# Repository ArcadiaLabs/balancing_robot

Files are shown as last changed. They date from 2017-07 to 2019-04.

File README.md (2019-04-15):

# Android Controlled Self Balancing Robot
Arduino + Android remote controlled balancing robot

This project is on Hackaday.io and takes part in the Hackaday Prize 2017 : https://hackaday.io/project/25835-android-controlled-balancing-robot
**Like this project on Hackaday.io and help me build new cool things !**

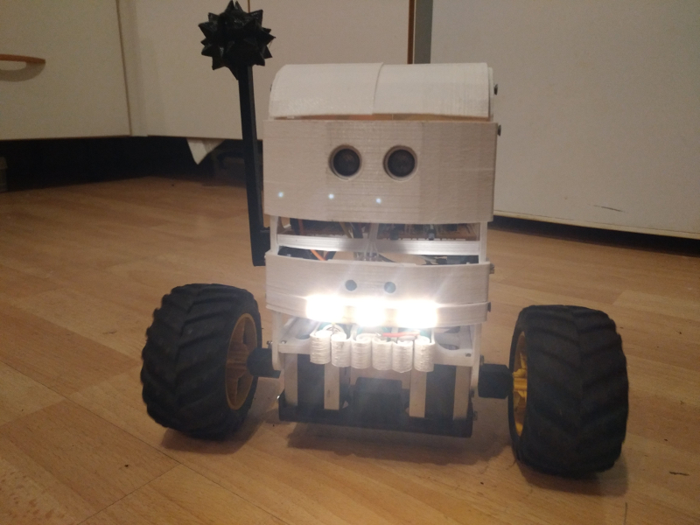
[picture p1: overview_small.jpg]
Overview


- Arduino pro micro (atmega32u4)
- Balance-Bot custom PCB
- MPU-9250 IMU
- HC-05 Bluetooth module
- 2x A4988 Stepper drivers
- 2x NEMA-17 Steppers Motors
- 1x 12g servo
- Custom 3D printed frame (and battle arm :D )
- 2x 5cm salvaged RC wheels

- Android : Bluetooth Electronics app (http://www.keuwl.com/apps/bluetoothelectronics/)

*You could find full instructions on the [project's page on HackaDay.io](https://hackaday.io/project/25835-android-controlled-balancing-robot) and in the README present in each subfolder of this repository.*

# Donation
If this project helps you reduce time to develop, you can buy me a cup of coffee :)



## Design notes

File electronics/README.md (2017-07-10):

# Android Controlled Self Balancing Robot - electronic circuit

This project is on Hackaday.io and takes part in the Hackaday Prize 2017 : https://hackaday.io/project/25835-android-controlled-balancing-robot
**Like this project on Hackaday.io and help me build new cool things !**

# Donation
If this project help you reduce time to develop, you can give me a cup of coffee :)



# LICENSE
Attribution-NonCommercial-NoDerivs 2.0 Generic (CC BY-NC-ND 2.0) Attribution-NonCommercial-NoDerivs 2.0 Generic (CC BY-NC-ND 2.0)

* You are free to:
    * **Share** — copy and redistribute the material in any medium or format

* Under the following terms:
    * **Attribution** — You must give appropriate credit, provide a link to the license, and indicate if changes were made. You may do so in any reasonable manner, but not in any way that suggests the licensor endorses you or your use.
    * **NonCommercial** — You may not use the material for commercial purposes.
    * **NoDerivatives** — If you remix, transform, or build upon the material, you may not distribute the modified material.
    * **No additional restrictions** — You may not apply legal terms or technological measures that legally restrict others from doing anything the license permits.

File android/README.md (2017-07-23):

# Android Controlled Self Balancing Robot - Android interface

This project is on Hackaday.io and takes part in the Hackaday Prize 2017 : https://hackaday.io/project/25835-android-controlled-balancing-robot
**Like this project on Hackaday.io and help me build new cool things !**

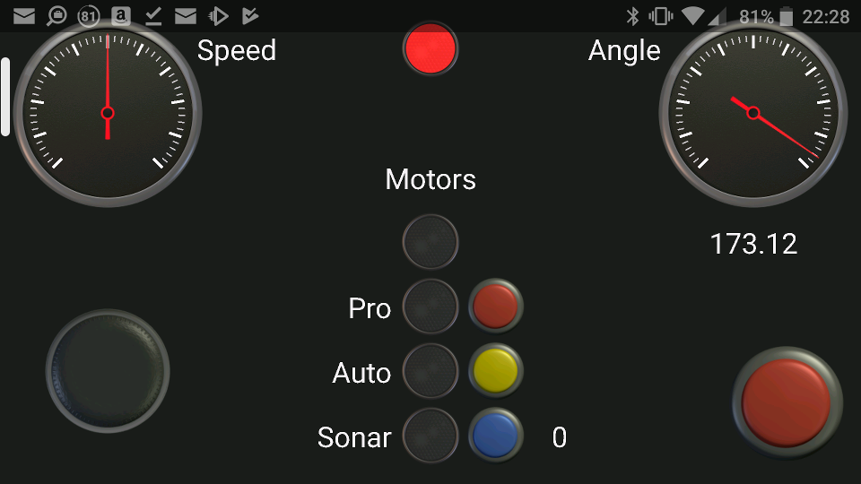
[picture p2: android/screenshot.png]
Android interface


The Android remote control interface uses the free [Kewlsoft Bluetooth Electronics app](https://play.google.com/store/apps/details?id=com.keuwl.arduinobluetooth).

## Instructions
- Install Bluetooth Electronics from the Play Store
- copt the brobot.kwl file from the repository to your android device, in keuwlsoft directory (usually located in /storage/emulated/0/keuwlsoft)
- Launch Bluetooth Electronics app
- Edit a new panel
- In the right menu, select Import/Export, and choose brobot.kwl
- Save
- Start the robot, connect to it from the app, enjoy !

## Controls
- The joystick on the left controls the robot
- The big red button on the right triggers the servo arm
- The little red button in the middle triggers pro mode on and off (be careful !)
- The little yellow button in the middle triggers the autonomous navigation on and off (if the robot is equiped with a IR sensor) 
- The little blue button in the middle triggers only the distance measurement on and off
- Two big indicators show robot speed and angle

# Donation
If this project help you reduce time to develop, you can give me a cup of coffee :)



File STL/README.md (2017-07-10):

# Android Controlled Self Balancing Robot - 3D files

This project is on Hackaday.io and takes part in the Hackaday Prize 2017 : https://hackaday.io/project/25835-android-controlled-balancing-robot
**Like this project on Hackaday.io and help me build new cool things !**

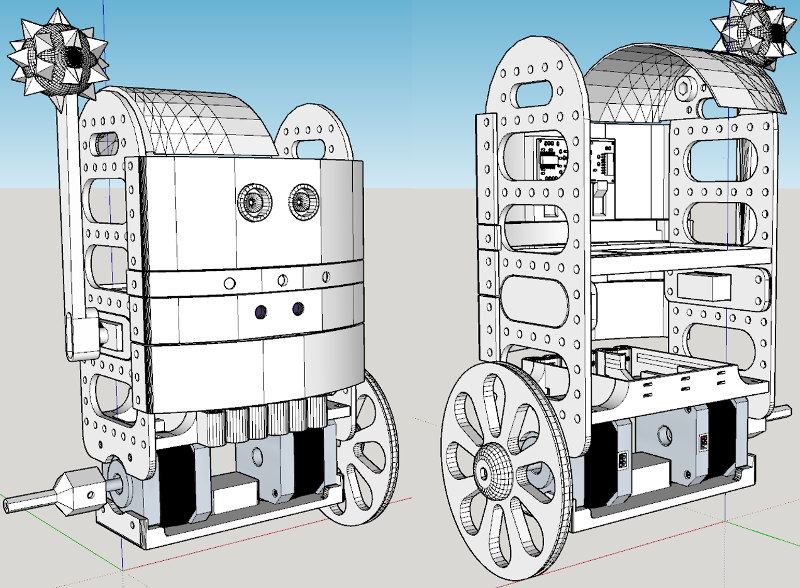
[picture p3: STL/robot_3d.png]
3D model


[3D files instructions](https://hackaday.io/project/25835-android-controlled-self-balancing-robot/log/62775-3d-printed-frame)

# Donation
If this project help you reduce time to develop, you can give me a cup of coffee :)



# LICENSE
Attribution-NonCommercial-NoDerivs 2.0 Generic (CC BY-NC-ND 2.0) Attribution-NonCommercial-NoDerivs 2.0 Generic (CC BY-NC-ND 2.0)

* You are free to:
    * **Share** — copy and redistribute the material in any medium or format

* Under the following terms:
    * **Attribution** — You must give appropriate credit, provide a link to the license, and indicate if changes were made. You may do so in any reasonable manner, but not in any way that suggests the licensor endorses you or your use.
    * **NonCommercial** — You may not use the material for commercial purposes.
    * **NoDerivatives** — If you remix, transform, or build upon the material, you may not distribute the modified material.
    * **No additional restrictions** — You may not apply legal terms or technological measures that legally restrict others from doing anything the license permits.

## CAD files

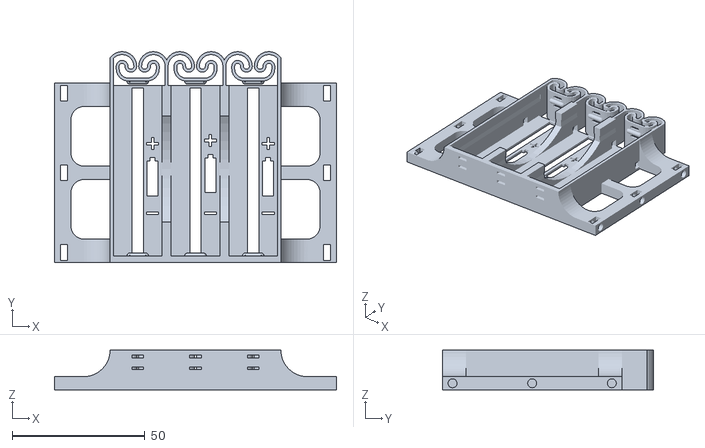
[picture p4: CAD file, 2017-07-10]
STL/battery_tray.stl
106.2 x 79.4 x 15.0

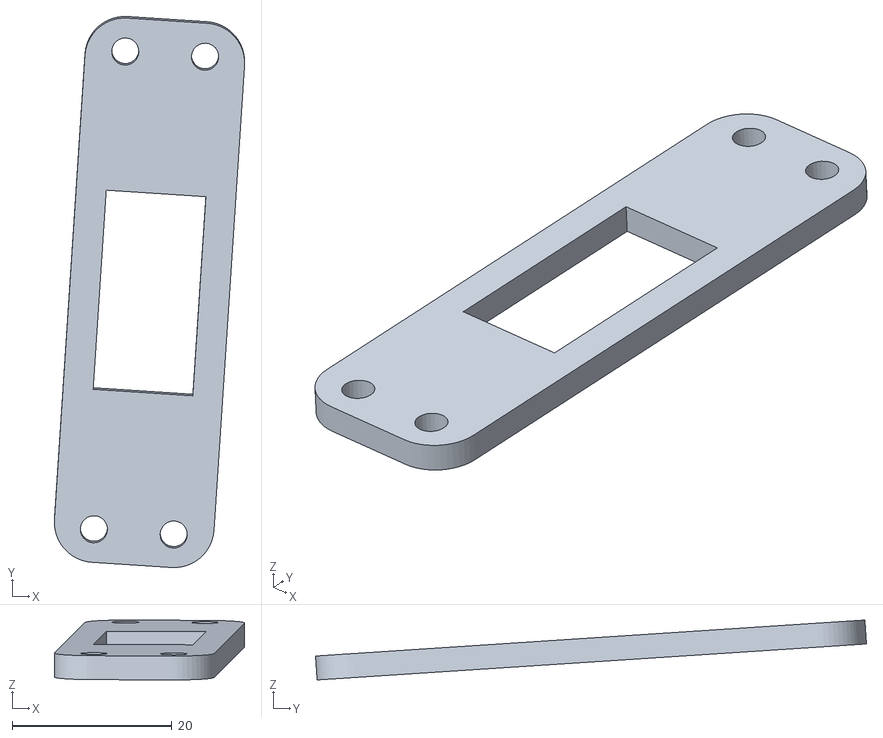
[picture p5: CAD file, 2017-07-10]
STL/servo_holder_part2.stl
23.8 x 68.9 x 7.50

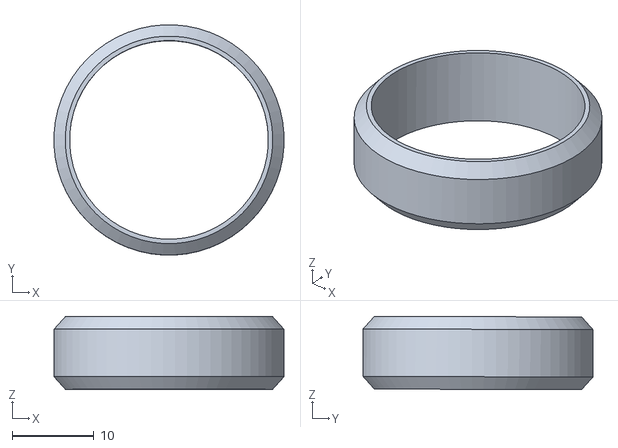
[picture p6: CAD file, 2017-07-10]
STL/arm_inner_ring.stl
28.2 x 28.2 x 9.00

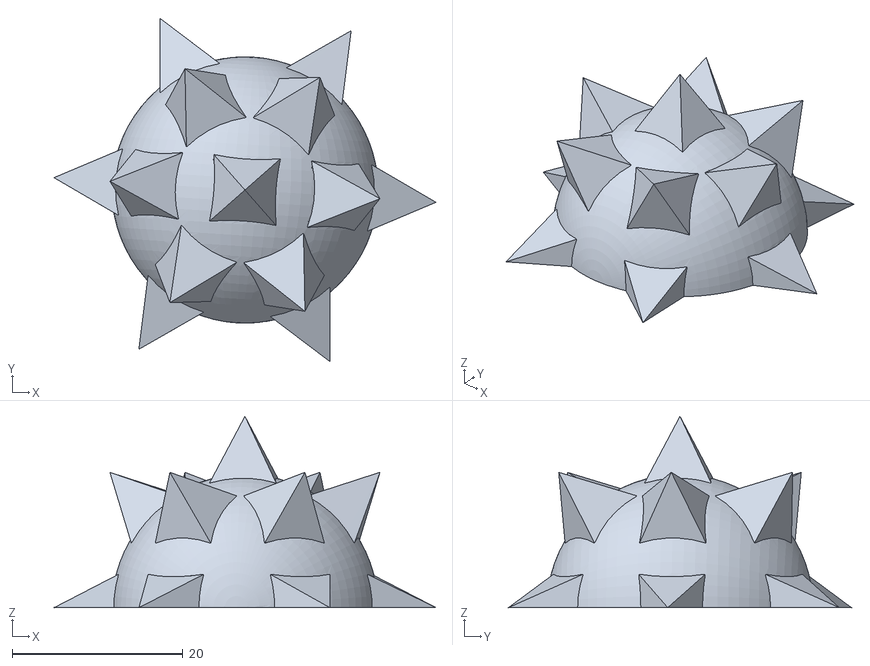
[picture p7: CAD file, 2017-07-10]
STL/arm_part2.stl
44.7 x 40.1 x 22.4

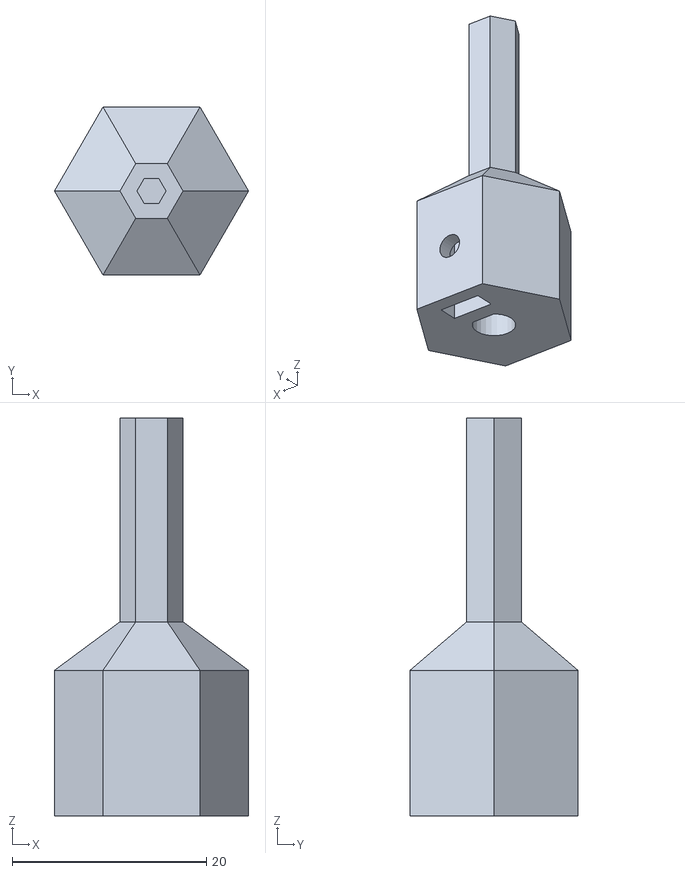
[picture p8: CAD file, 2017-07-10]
STL/shaft_drive.stl
20.0 x 17.3 x 41.0

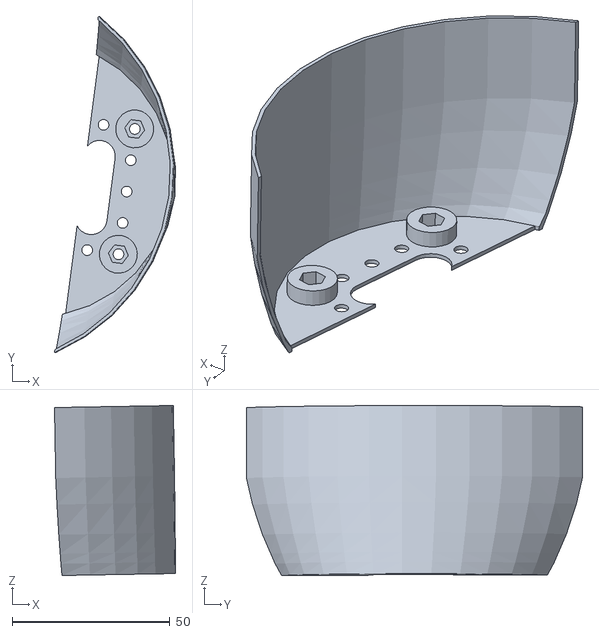
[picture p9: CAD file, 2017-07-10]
STL/helmet.stl
38.3 x 106.4 x 53.8

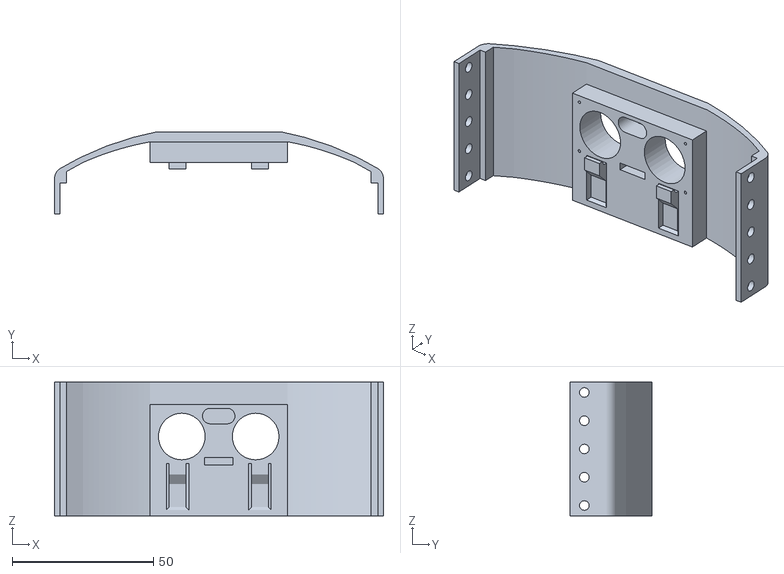
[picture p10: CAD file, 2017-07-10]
STL/bumper5_sr_04.stl
116.4 x 29.0 x 47.4

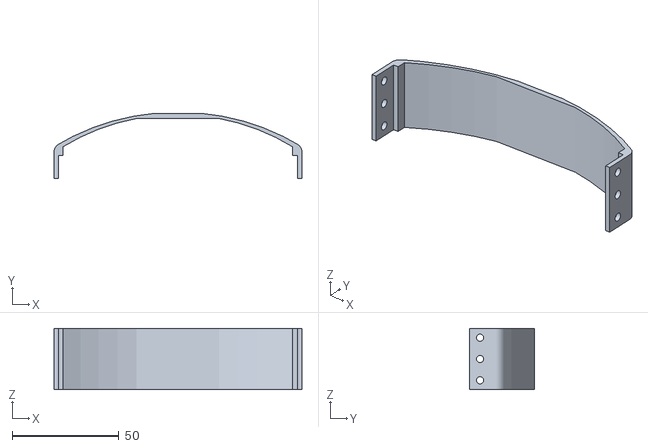
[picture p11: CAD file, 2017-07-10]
STL/bumper3.stl
116.4 x 30.7 x 28.8

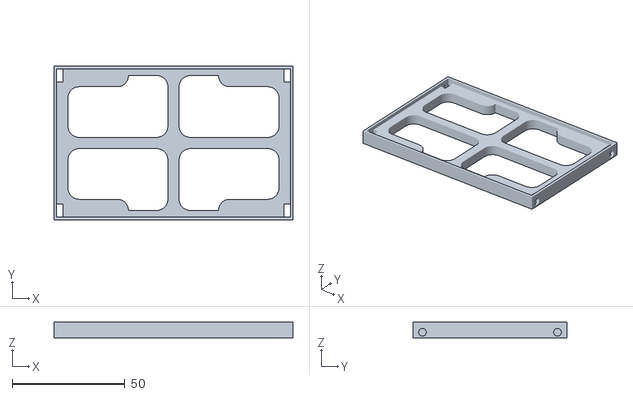
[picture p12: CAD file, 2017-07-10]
STL/tray_large.stl
106.2 x 68.3 x 7.00

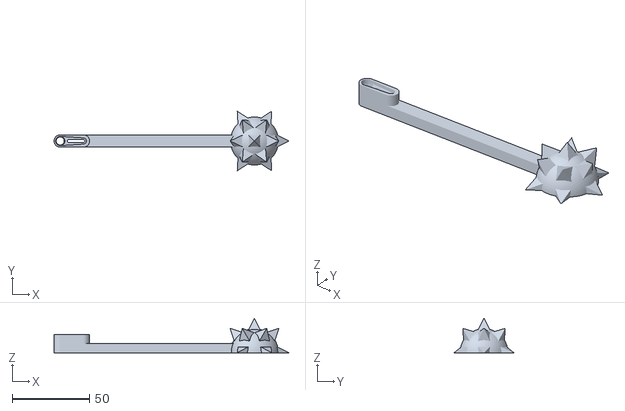
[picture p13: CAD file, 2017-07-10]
STL/arm_part1.stl
152.4 x 38.8 x 22.4

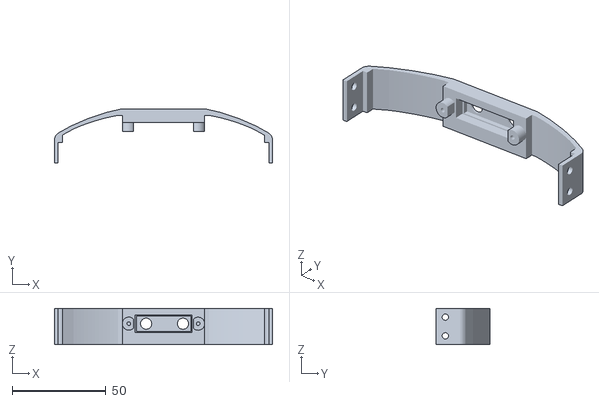
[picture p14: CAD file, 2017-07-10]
STL/bumper2_ir_sensor.stl
116.4 x 29.0 x 19.4

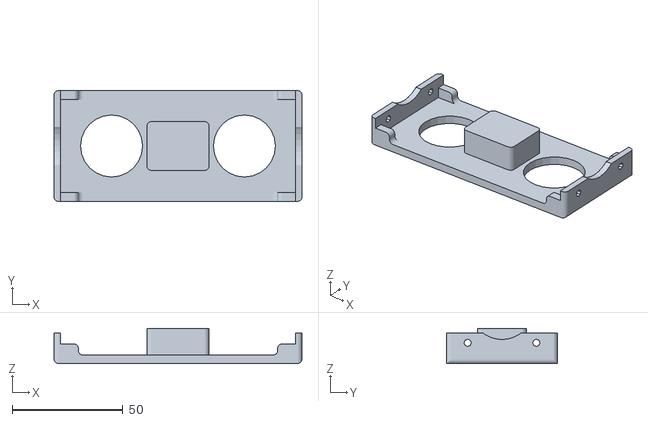
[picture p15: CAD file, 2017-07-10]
STL/motors_plate.stl
112.0 x 50.0 x 15.9

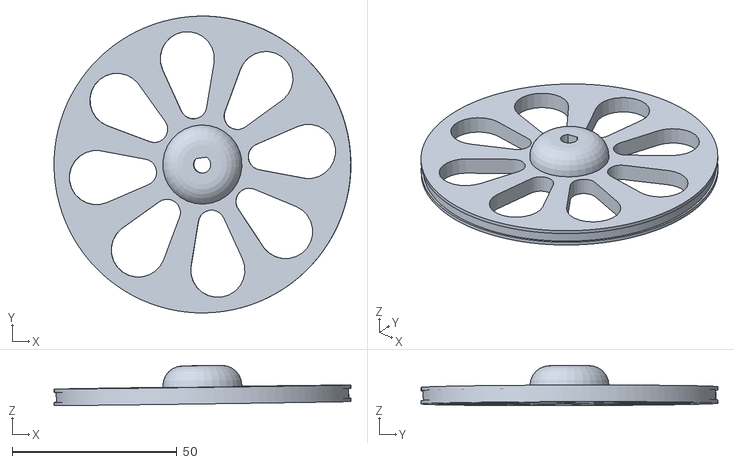
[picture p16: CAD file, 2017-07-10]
STL/wheel.stl
90.0 x 90.0 x 12.2

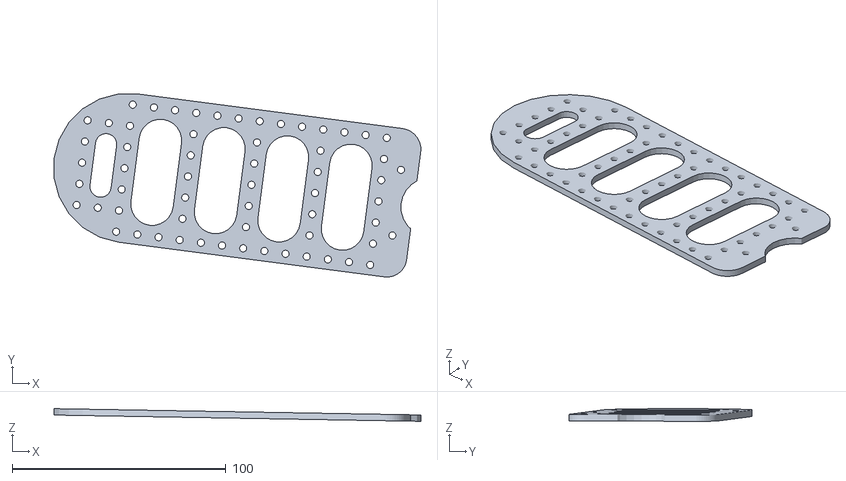
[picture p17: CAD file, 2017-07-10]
STL/body_side.stl
171.9 x 85.7 x 5.95

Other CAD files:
STL/tool_wrench.stl
STL/servo_holder_part1.stl
STL/tray_small.stl
STL/bumper1_leds_strip.stl

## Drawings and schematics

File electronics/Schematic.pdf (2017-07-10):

## VCC

+5V

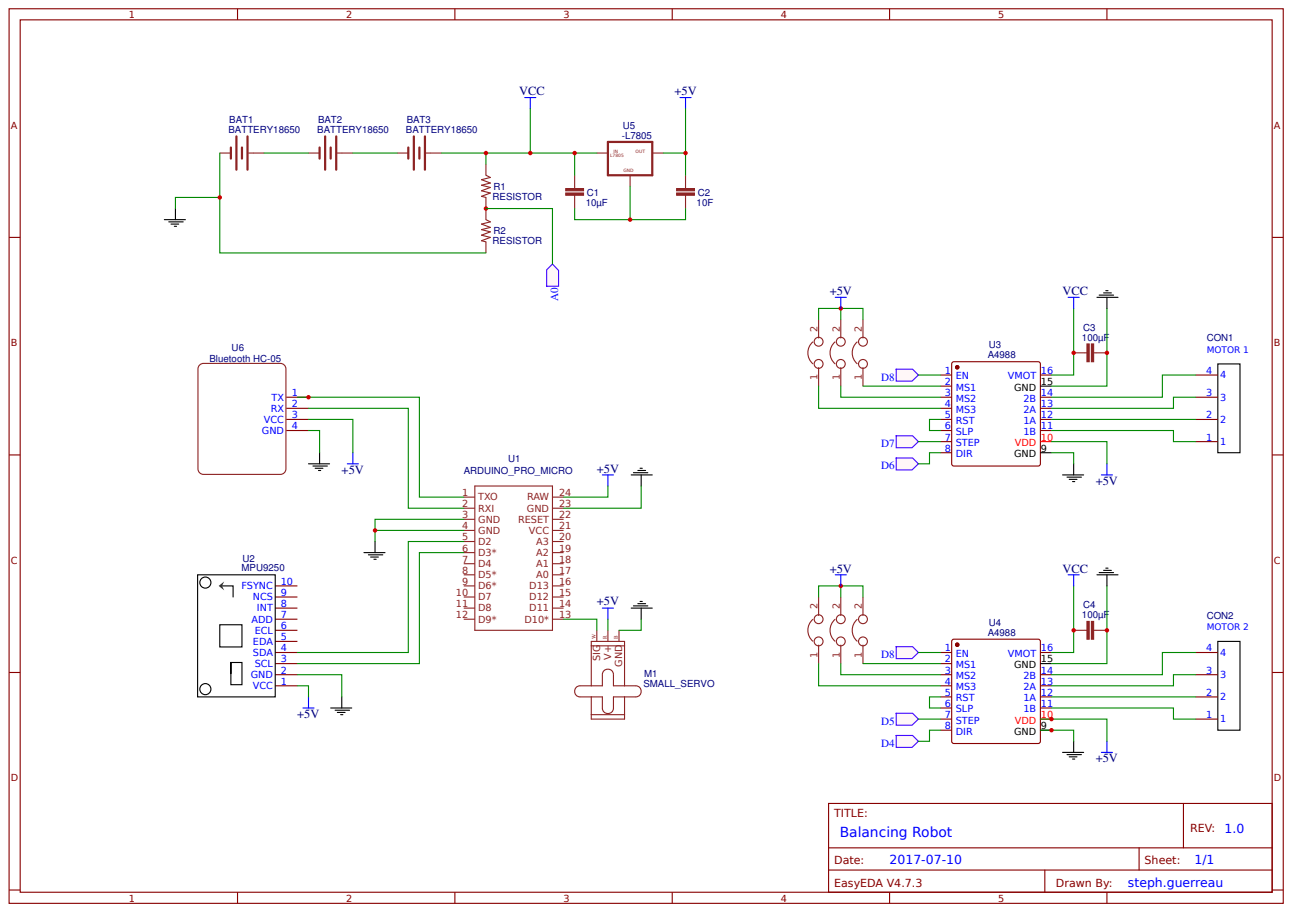
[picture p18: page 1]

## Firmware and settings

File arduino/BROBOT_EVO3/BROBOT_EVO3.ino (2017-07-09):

// BROBOT EVO 2
// SELF BALANCE ARDUINO ROBOT WITH STEPPER MOTORS

// -- HARDWARE --
// BROBOT ELECTRONIC BRAIN SHIELD : Arduino pro micro + MPU9250/6050 (I2C) IMU
//      + HC-05 / HC-06 Bluetooth module + 2x A4988 STEPPER MOTOR drivers
// STEPPER MOTORS : 2x NEMA-17
// OPTIONAL : 1x 12g servo (ES08MA-II recommended)

// -- HOW TO USE --
// The robot needs at least 10-15 seconds with no motion (robot steady) at startup to give good values...
// Put the robot at horizontal then switch it ON. It will indicate when ready with 3 small motors and servo movement.

// The robot is OFF when the angle is high (robot is horizontal). When you start raising up the robot, it
// automatically switches ON and starts a RAISE UP procedure.
// You could RAISE UP the robot manually or using the robot servo actuated arm (Servo button on the interface)
// To switch OFF the robot you could manually put the robot down on the floor (horizontal)

// -- ADDITIONAL DETAILS --
// This code doesn´t need external libraries except Wire.h

// This code requires 2x 16-bit timers for motors control, so a ATmega32u4 based arduino is mandatory (Micro, Leonardo)
// An ATmega168/328 WON'T WORK ! (only 1x 16-bit timer)

// Angle estimation using complementary filter (fusion between gyro and accel)
// Angle calculations and control part is running at 100Hz

// We use a standard PID controllers (Proportional, Integral derivative controller) for robot stability
// We have a PI controller for speed control and a PD controller for stability (robot angle)
// The output of the control (motors speed) is integrated so it´s really an acceleration, not an speed.

// Based on BROBOT EVO 2 code by JJROBOTS (Version 2.8 dated 08/03/2017)
// Author: JJROBOTS.COM
// License: GPL v2
// Original Project URL: http://jjrobots.com/b-robot

#include <Wire.h>

// -- SETTINGS --
// NORMAL MODE SETTINGS (MAXIMUN SETTINGS)
#define MAX_THROTTLE 550
#define MAX_STEERING 140
#define MAX_TARGET_ANGLE 14

// PRO MODE = MORE AGGRESSIVE (MAXIMUN SETTINGS)
#define MAX_THROTTLE_PRO 860 
#define MAX_STEERING_PRO 280
#define MAX_TARGET_ANGLE_PRO 20 
//#define MAX_TARGET_ANGLE_PRO 32 

// Default control terms
#define KP 0.32       
#define KD 0.050     
#define KP_THROTTLE 0.075 
#define KI_THROTTLE 0.1 
#define KP_POSITION 0.06  
#define KD_POSITION 0.45  

// Control gains for raiseup (the raiseup movement requiere special control parameters)
#define KP_RAISEUP 0.1   
#define KD_RAISEUP 0.16   
#define KP_THROTTLE_RAISEUP 0   // No speed control on raiseup
#define KI_THROTTLE_RAISEUP 0.0

#define MAX_CONTROL_OUTPUT 500
#define ITERM_MAX_ERROR 30   // Iterm windup constants for PI control 
#define ITERM_MAX 10000

#define ANGLE_OFFSET -1.0  // Offset angle for balance (to compensate robot own weitght distribution)

#define ZERO_SPEED 65535
#define MAX_ACCEL 15      // Maximun motor acceleration (MAX RECOMMENDED VALUE: 20) (default:15)

#define MICROSTEPPING 16   // 8 or 16 for 1/8 or 1/16 driver microstepping (default:16)

// Servo definitions
#define SERVO_AUX_NEUTRAL 1630  // Servo neutral position
#define SERVO_MIN_PULSEWIDTH 700
#define SERVO_MAX_PULSEWIDTH 2500

#define ANGLE_READY_SERVO 80    // Startup angle using servo raiseup
#define ANGLE_READY_NOSERVO 76  // Startup angle using normal raiseup

//*** PINS
// MOTORS
int MOTORS_ENABLE = 8;
// If you change these pins, please also adapt functions in 'Control' page accordingly
int MOTOR1_STEP = 7;  // STEP MOTOR 1 PORTE,6
int MOTOR1_DIR = 6;   // DIR MOTOR 1  PORTD,7
int MOTOR2_STEP = 5;  // STEP MOTOR 2 PORTC,6
int MOTOR2_DIR = 4;   // DIR MOTOR 2  PORTD,4
// gp2y0a21f sensor
int IR_PIN = A3;
// SERVO
// If you change this pin, please also adapt functions in 'servo' page accordingly
int SERVO = 10;  // SERVO

// AUTONOMOUS MODE DISTANCE PARAMETERS
int OBSTACLE_DISTANCE_MIN = 50;
int WALK_DISTANCE_MIN = 80;

#define DEBUG 0   // 0 = No debug info (default) DEBUG 1 for console output

// AUX definitions
#define CLR(x,y) (x&=(~(1<<y)))
#define SET(x,y) (x|=(1<<y))
#define RAD2GRAD 57.2957795
#define GRAD2RAD 0.01745329251994329576923690768489

uint8_t cascade_control_loop_counter = 0;
uint8_t fast_loop_counter;      // To generate a fast loop 40Hz
uint8_t medium_loop_counter;           // To generate a medium loop 7.5Hz
uint8_t slow_loop_counter;      // To generate a slow loop 2Hz

uint8_t sendBattery_counter; // To send battery status

int16_t BatteryValue;

long timer_old;
long timer_value;
float debugVariable;
float dt;

// Angle of the robot (used for stability control)
float angle_adjusted;
float angle_adjusted_Old;

// Default control values from constant definitions
float Kp = KP;
float Kd = KD;
float Kp_thr = KP_THROTTLE;
float Ki_thr = KI_THROTTLE;
float Kp_user = KP;
float Kd_user = KD;
float Kp_thr_user = KP_THROTTLE;
float Ki_thr_user = KI_THROTTLE;
float Kp_position = KP_POSITION;
float Kd_position = KD_POSITION;
bool newControlParameters = false;
bool modifing_control_parameters = false;
int16_t position_error_sum_M1;
int16_t position_error_sum_M2;
float PID_errorSum;
float PID_errorOld = 0;
float PID_errorOld2 = 0;
float setPointOld = 0;
float target_angle;
int16_t throttle;
float steering;
float max_throttle = MAX_THROTTLE;
float max_steering = MAX_STEERING;
float max_target_angle = MAX_TARGET_ANGLE;
float control_output;

boolean positionControlMode = false;
uint8_t mode;  // mode = 0 Normal mode, mode = 1 Pro mode (More agressive)

int16_t motor1;
int16_t motor2;

// position control
volatile int32_t steps1;
volatile int32_t steps2;
int32_t target_steps1;
int32_t target_steps2;
int16_t motor1_control;
int16_t motor2_control;

// motors speeds
int16_t speed_M1, speed_M2;        // Actual speed of motors
int8_t  dir_M1, dir_M2;            // Actual direction of steppers motors
int16_t actual_robot_speed;        // overall robot speed (measured from steppers speed)
int16_t actual_robot_speed_Old;
float estimated_speed_filtered;    // Estimated robot speed

// IR sensor distance
long ir_distance = 0;  // IR sensor real distance (cm)

// autonomous mode
uint8_t autonomous_mode_status;   // 1: NORMAL STATUS=Walking  2: 
int16_t autonomous_mode_counter;  
int16_t autonomous_mode_distance;

boolean motors_on=false;
boolean acro_on=false;
boolean auto_on=false;
boolean ir_on=false;
boolean servo_on=false;

// INITIALIZATION
void setup()
{
  // VOLTAGE PIN INIT
  pinMode(A0, INPUT); 
  
  // STEPPERS PINS INIT
  pinMode(MOTORS_ENABLE, OUTPUT); // ENABLE MOTORS
  
  pinMode(MOTOR1_STEP, OUTPUT); 
  pinMode(MOTOR1_DIR, OUTPUT); 

  pinMode(MOTOR2_STEP, OUTPUT); 
  pinMode(MOTOR2_DIR, OUTPUT); 

  // SONAR PINS INIT
  pinMode(IR_PIN, INPUT);

  // SERVO INIT
  pinMode(SERVO, OUTPUT);
  
//  digitalWrite(MOTORS_ENABLE, HIGH);  // Disable motors
  Motors_Enable(false);

  Serial.begin(115200);     // Serial output to console
  Serial1.begin(57600);    // Serial telemetry / controls to bluetooth

  // Init virtual LEDs
  Serial1.print("*LR255G0B0*"); // *Ready* virtual LED : red
  Serial1.print("*BR0G0B0*");   // *Battery low* virtual LED : black (off)
  Serial1.print("*WR0G0B0*");   // *Battery warning* virtual LED : black (off)
  
  // Initialize I2C bus (MPU6050 is connected via I2C)
  Wire.begin();

  #if DEBUG > 0
    delay(9000);
  #else
    delay(1000);
  #endif
    Serial.println("BROBOT by JJROBOTS v2.8");

  delay(200);
  Serial.println("Don't move for 10 sec...");
  MPU6050_setup();  // setup MPU6050 IMU
  delay(500);

  // Calibrate gyros
  MPU6050_calibrate();

  // SERVO INITIALIZATION
  Serial.println("Servo init");
  BROBOT_initServo();
  BROBOT_moveServo(SERVO_AUX_NEUTRAL);

  // STEPPER MOTORS INITIALIZATION
  Serial.println("Steppers init");
  // MOTOR1 => TIMER1
  TCCR1A = 0;                       // Timer1 CTC mode 4, OCxA,B outputs disconnected
  TCCR1B = (1 << WGM12) | (1 << CS11); // Prescaler=8, => 2Mhz
  OCR1A = ZERO_SPEED;               // Motor stopped
  dir_M1 = 0;
  TCNT1 = 0;

  // MOTOR2 => TIMER3
  TCCR3A = 0;                       // Timer3 CTC mode 4, OCxA,B outputs disconnected
  TCCR3B = (1 << WGM32) | (1 << CS31); // Prescaler=8, => 2Mhz
  OCR3A = ZERO_SPEED;   // Motor stopped
  dir_M2 = 0;
  TCNT3 = 0;
  delay(200);

  // Enable stepper drivers and TIMER interrupts
  Motors_Enable(true);
  // Enable TIMERs interrupts
  TIMSK1 |= (1 << OCIE1A); // Enable Timer1 interrupt
  TIMSK3 |= (1 << OCIE1A); // Enable Timer1 interrupt

  // Little motor vibration and servo move to indicate that robot is ready
  for (uint8_t k = 0; k < 5; k++)
  {
    setMotorSpeedM1(5);
    setMotorSpeedM2(5);
    BROBOT_moveServo(SERVO_AUX_NEUTRAL + 100);
    delay(200);
    setMotorSpeedM1(-5);
    setMotorSpeedM2(-5);
    BROBOT_moveServo(SERVO_AUX_NEUTRAL - 100);
    delay(200);
  }
  BROBOT_moveServo(SERVO_AUX_NEUTRAL);

  Serial.println("Start...");
  timer_old = micros();

  // *Ready* virtual LED : green
  Serial1.print("*LR0G255B0*");
}


// MAIN LOOP
void loop()
{

  BT_MsgRead();
  
  // AUTONOMOUS MODE
  if (auto_on == true){
    autonomousMode();
  }
  
  timer_value = micros();
    
  // New IMU data?
  if (MPU6050_newData())
  {
    MPU6050_read_3axis();

//    // Increment loop counters
    fast_loop_counter++;
    medium_loop_counter++;
    slow_loop_counter++;
    
    dt = (timer_value - timer_old) * 0.000001; // dt in seconds
    timer_old = timer_value;

    angle_adjusted_Old = angle_adjusted;
    // Get new orientation angle from IMU (MPU6050)
    angle_adjusted = MPU6050_getAngle(dt) + ANGLE_OFFSET;

    

#if DEBUG==1
    Serial.print(dt);
    Serial.print(" ");
    Serial.println(angle_adjusted);
#endif
    //Serial.print("\t");

    // We calculate the estimated robot speed:
    // Estimated_Speed = angular_velocity_of_stepper_motors(combined) - angular_velocity_of_robot(angle measured by IMU)
    actual_robot_speed = (speed_M1 + speed_M2) / 2; // Positive: forward  

    int16_t angular_velocity = (angle_adjusted - angle_adjusted_Old) * 25.0; // 25 is an empirical extracted factor to adjust for real units
    int16_t estimated_speed = -actual_robot_speed + angular_velocity;
    estimated_speed_filtered = estimated_speed_filtered * 0.9 + (float)estimated_speed * 0.1; // low pass filter on estimated speed

#if DEBUG==2
    Serial.print(angle_adjusted);
    Serial.print(" ");
    Serial.println(estimated_speed_filtered);
#endif

    if (positionControlMode)
    {
      
      // POSITION CONTROL. INPUT: Target steps for each motor. Output: motors speed
      motor1_control = positionPDControl(steps1, target_steps1, Kp_position, Kd_position, speed_M1);
      motor2_control = positionPDControl(steps2, target_steps2, Kp_position, Kd_position, speed_M2);

      // Convert from motor position control to throttle / steering commands
      throttle = (motor1_control + motor2_control) / 2;
      throttle = constrain(throttle, -190, 190);
      steering = motor2_control - motor1_control;
      steering = constrain(steering, -50, 50);

    }

    // ROBOT SPEED CONTROL: This is a PI controller.
    //    input:user throttle(robot speed), variable: estimated robot speed, output: target robot angle to get the desired speed
    target_angle = speedPIControl(dt, estimated_speed_filtered, throttle, Kp_thr, Ki_thr);
    target_angle = constrain(target_angle, -max_target_angle, max_target_angle); // limited output


#if DEBUG==3
    Serial.print(angle_adjusted);
    Serial.print(" ");
    Serial.print(estimated_speed_filtered);
    Serial.print(" ");
    Serial.println(target_angle);
#endif

    // Stability control (100Hz loop): This is a PD controller.
    //    input: robot target angle(from SPEED CONTROL), variable: robot angle, output: Motor speed
    //    We integrate the output (sumatory), so the output is really the motor acceleration, not motor speed.
    control_output += stabilityPDControl(dt, angle_adjusted, target_angle, Kp, Kd);
    control_output = constrain(control_output, -MAX_CONTROL_OUTPUT, MAX_CONTROL_OUTPUT); // Limit max output from control

    // The steering part from the user is injected directly to the output
    motor1 = control_output + steering;
    motor2 = control_output - steering;

    // Limit max speed (control output)
    motor1 = constrain(motor1, -MAX_CONTROL_OUTPUT, MAX_CONTROL_OUTPUT);
    motor2 = constrain(motor2, -MAX_CONTROL_OUTPUT, MAX_CONTROL_OUTPUT);

    int angle_ready;
    if (servo_on == true) {    // If we press the SERVO button we start to move
      angle_ready = ANGLE_READY_SERVO;
//      angle_ready = 80;
    }
    else {
      angle_ready = ANGLE_READY_NOSERVO;
//      angle_ready = 74;  // Default angle
    }
    if ((angle_adjusted < angle_ready) && (angle_adjusted > -angle_ready)) // Is robot ready (upright?)
    {
            
      // NORMAL MODE
      Motors_Enable(true);
      // NOW we send the commands to the motors
      setMotorSpeedM1(motor1);
      setMotorSpeedM2(motor2);
      

      #if DEBUG==4
        Serial.print(angle_adjusted);
        Serial.print(" ");
        Serial.print(estimated_speed_filtered);
        Serial.print(" ");
        Serial.print(target_angle);
        Serial.print(" ");
        Serial.print(throttle);
        Serial.print(" ");
        Serial.println(steering);
      #endif
    }
    else   // Robot not ready (flat), angle > angle_ready => ROBOT OFF
    {
//      digitalWrite(MOTORS_ENABLE, HIGH);  // Disable motors
      Motors_Enable(false);
//      setMotorSpeedM1(0);
//      setMotorSpeedM2(0);
      PID_errorSum = 0;  // Reset PID I term
      Kp = KP_RAISEUP;   // CONTROL GAINS FOR RAISE UP
      Kd = KD_RAISEUP;
      Kp_thr = KP_THROTTLE_RAISEUP;
      Ki_thr = KI_THROTTLE_RAISEUP;
      // RESET steps
      steps1 = 0;
      steps2 = 0;

      #if DEBUG==4
        Serial.print(angle_adjusted);
        Serial.print(" ");
        Serial.print(estimated_speed_filtered);
        Serial.print(" ");
        Serial.print(target_angle);
        Serial.println(" 0 0");
      #endif
    }

    // Push1 Move servo arm
    if (servo_on == true)  // Move arm
    {
      if (angle_adjusted > -40) {
        BROBOT_moveServo(SERVO_MIN_PULSEWIDTH);
      }
      else {
        BROBOT_moveServo(SERVO_MAX_PULSEWIDTH);
      }
    }
    else {
      BROBOT_moveServo(SERVO_AUX_NEUTRAL);
    }

    // Normal condition?
    if ((angle_adjusted < 56) && (angle_adjusted > -56))
    {
      Kp = Kp_user;            // Default user control gains
      Kd = Kd_user;
      Kp_thr = Kp_thr_user;
      Ki_thr = Ki_thr_user;
    }
    else    // We are in the raise up procedure => we use special control parameters
    {
      Kp = KP_RAISEUP;         // CONTROL GAINS FOR RAISE UP
      Kd = KD_RAISEUP;
      Kp_thr = KP_THROTTLE_RAISEUP;
      Ki_thr = KI_THROTTLE_RAISEUP;
    }
    
    BT_MsgSend();

  } // End of new IMU data

//  //*** Fast loop 40Hz
  if (fast_loop_counter >= 5)
  {
    fast_loop_counter = 0;
  } // End of Fast loop
  
  //*** Medium loop 7.5Hz
  if (medium_loop_counter >= 15)
  {
    medium_loop_counter = 0;
    if (ir_on == true){
      IR_Read();
    }  
  } // End of medium loop

  //*** Slow loop 1Hz
  else if (slow_loop_counter >= 1000) // 1Hz
  {
//    Serial.println("loop");
    slow_loop_counter = 0;
  }  // End of slow loop

}

void Motors_Enable(bool state){
  if (state == true){
    digitalWrite(MOTORS_ENABLE, LOW);  // Enable motors
    motors_on = true;
  }
  else{
    digitalWrite(MOTORS_ENABLE, HIGH);  // Disable motors
    setMotorSpeedM1(0);
    setMotorSpeedM2(0);
    motors_on = false;
  }
}

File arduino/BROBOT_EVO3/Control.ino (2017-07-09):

// BROBOT EVO 2 by JJROBOTS
// SELF BALANCE ARDUINO ROBOT WITH STEPPER MOTORS
// License: GPL v2
// Control functions (PID controls, Steppers control...)

// PD controller implementation(Proportional, derivative). DT in seconds
float stabilityPDControl(float DT, float input, float setPoint,  float Kp, float Kd)
{
  float error;
  float output;

  error = setPoint - input;

  // Kd is implemented in two parts
  //    The biggest one using only the input (sensor) part not the SetPoint input-input(t-1).
  //    And the second using the setpoint to make it a bit more agressive   setPoint-setPoint(t-1)
  float Kd_setPoint = constrain((setPoint - setPointOld), -8, 8); // We limit the input part...
  output = Kp * error + (Kd * Kd_setPoint - Kd * (input - PID_errorOld)) / DT;
  //Serial.print(Kd*(error-PID_errorOld));Serial.print("\t");
  //PID_errorOld2 = PID_errorOld;
  PID_errorOld = input;  // error for Kd is only the input component
  setPointOld = setPoint;
  return (output);
}


// PI controller implementation (Proportional, integral). DT in seconds
float speedPIControl(float DT, int16_t input, int16_t setPoint,  float Kp, float Ki)
{
  int16_t error;
  float output;

  error = setPoint - input;
  PID_errorSum += constrain(error, -ITERM_MAX_ERROR, ITERM_MAX_ERROR);
  PID_errorSum = constrain(PID_errorSum, -ITERM_MAX, ITERM_MAX);

  //Serial.println(PID_errorSum);

  output = Kp * error + Ki * PID_errorSum * DT; // DT is in miliseconds...
  return (output);
}


float positionPDControl(long actualPos, long setPointPos, float Kpp, float Kdp, int16_t speedM)
{
  float output;
  float P;

  P = constrain(Kpp * float(setPointPos - actualPos), -115, 115); // Limit command
  output = P + Kdp * float(speedM);
  return (output);
}

// TIMER 1 : STEPPER MOTOR1 SPEED CONTROL
ISR(TIMER1_COMPA_vect)
{
  if (dir_M1 == 0) // If we are not moving we dont generate a pulse
    return;
  // We generate 1us STEP pulse
  SET(PORTE, 6); // STEP MOTOR 1
  //delay_1us();
  if (dir_M1 > 0)
    steps1--;
  else
    steps1++;
  CLR(PORTE, 6);
}
// TIMER 3 : STEPPER MOTOR2 SPEED CONTROL
ISR(TIMER3_COMPA_vect)
{
  if (dir_M2 == 0) // If we are not moving we dont generate a pulse
    return;
  // We generate 1us STEP pulse
  SET(PORTC, 6); // STEP MOTOR 2
  //delay_1us();
  if (dir_M2 > 0)
    steps2--;
  else
    steps2++;
  CLR(PORTC, 6);
}


// Set speed of Stepper Motor1
// tspeed could be positive or negative (reverse)
void setMotorSpeedM1(int16_t tspeed)
{
  long timer_period;
  int16_t speed;

  // Limit max speed?

  // WE LIMIT MAX ACCELERATION of the motors
  if ((speed_M1 - tspeed) > MAX_ACCEL)
    speed_M1 -= MAX_ACCEL;
  else if ((speed_M1 - tspeed) < -MAX_ACCEL)
    speed_M1 += MAX_ACCEL;
  else
    speed_M1 = tspeed;

#if MICROSTEPPING==16
  speed = speed_M1 * 50; // Adjust factor from control output speed to real motor speed in steps/second
#else
  speed = speed_M1 * 25; // 1/8 Microstepping
#endif

  if (speed == 0)
  {
    timer_period = ZERO_SPEED;
    dir_M1 = 0;
  }
  else if (speed > 0)
  {
    timer_period = 2000000 / speed; // 2Mhz timer
    dir_M1 = 1;
    SET(PORTD, 7); // DIR Motor 1 (Forward)
  }
  else
  {
    timer_period = 2000000 / -speed;
    dir_M1 = -1;
    CLR(PORTD, 7); // Dir Motor 1
  }
  if (timer_period > 65535)   // Check for minimun speed (maximun period without overflow)
    timer_period = ZERO_SPEED;

  OCR1A = timer_period;
  // Check  if we need to reset the timer...
  if (TCNT1 > OCR1A)
    TCNT1 = 0;
}

// Set speed of Stepper Motor2
// tspeed could be positive or negative (reverse)
void setMotorSpeedM2(int16_t tspeed)
{
  long timer_period;
  int16_t speed;

  // Limit max speed?

  // WE LIMIT MAX ACCELERATION of the motors
  if ((speed_M2 - tspeed) > MAX_ACCEL)
    speed_M2 -= MAX_ACCEL;
  else if ((speed_M2 - tspeed) < -MAX_ACCEL)
    speed_M2 += MAX_ACCEL;
  else
    speed_M2 = tspeed;

#if MICROSTEPPING==16
  speed = speed_M2 * 50; // Adjust factor from control output speed to real motor speed in steps/second
#else
  speed = speed_M2 * 25; // 1/8 Microstepping
#endif

  if (speed == 0)
  {
    timer_period = ZERO_SPEED;
    dir_M2 = 0;
  }
  else if (speed > 0)
  {
    timer_period = 2000000 / speed; // 2Mhz timer
    dir_M2 = 1;
    CLR(PORTD, 4);   // Dir Motor2 (Forward)
  }
  else
  {
    timer_period = 2000000 / -speed;
    dir_M2 = -1;
    SET(PORTD, 4);  // DIR Motor 2
  }
  if (timer_period > 65535)   // Check for minimun speed (maximun period without overflow)
    timer_period = ZERO_SPEED;

  OCR3A = timer_period;
  // Check  if we need to reset the timer...
  if (TCNT3 > OCR3A)
    TCNT3 = 0;
}

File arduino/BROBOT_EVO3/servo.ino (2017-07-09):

// Default servo definitions
//#define SERVO_AUX_NEUTRAL 1500  // Servo neutral position
//#define SERVO_MIN_PULSEWIDTH 700
//#define SERVO_MAX_PULSEWIDTH 2300

// Init servo on T4 timer. Output OC4B / PB6 (Micro / Leonardo Pin10)
// We configure the Timer4 for 11 bits PWM (enhanced precision) and 16.3ms period (OK for most servos)
// Resolution: 8us per step (this is OK for servos, around 175 steps for typical servo)
void BROBOT_initServo()
{
int temp;

  // Initialize Timer4 as Fast PWM
  TCCR4A = (1<<PWM4A)|(1<<PWM4B);
  TCCR4B = 0;
  TCCR4C = (1<<PWM4D);
  TCCR4D = 0;
  TCCR4E = (1<<ENHC4); // Enhanced -> 11 bits

  temp = 1500>>3;
  TC4H = temp >> 8;
  OCR4B = temp & 0xff;

  // Reset timer
  TC4H = 0;
  TCNT4 = 0;

  // Set TOP to 1023 (10 bit timer)
  TC4H = 3;
  OCR4C = 0xFF;

  // OC4B = PB6 (Pin10)
  // Set pin as output
  DDRB |= (1 << 6);  // OC4B = PB6 (Pin10 on Leonardo board)

  //Enable OC4B / PB6 (Pin10) output
  TCCR4A |= (1<<COM4B1); 

  // -- ORIGINAL BB-ROBOT --
  // OC4A = PC7 (Pin13)  OC4B = PB6 (Pin10)   OC4D = PD7 (Pin6)
  // Set pins as outputs
//  DDRB |= (1 << 6);  // OC4B = PB6 (Pin10 on Leonardo board)
//  DDRC |= (1 << 7);  // OC4A = PC7 (Pin13 on Leonardo board)
//  DDRD |= (1 << 7);  // OC4D = PD7 (Pin6 on Leonardo board)

//  //Enable OC4A and OC4B and OCR4D output
//  TCCR4A |= (1<<COM4B1)|(1<<COM4A1);
//  TCCR4C |= (1<<COM4D1);
  // -- ORIGINAL BB-ROBOT END --

  // set prescaler to 256 and enable timer    16Mhz/256/1024 = 61Hz (16.3ms)
  TCCR4B = (1 << CS43)|(1 << CS40);
}

void BROBOT_moveServo(int pwm)
{
  pwm = constrain(pwm,SERVO_MIN_PULSEWIDTH,SERVO_MAX_PULSEWIDTH)>>3;  // Check max values and Resolution: 8us
  // 11 bits => 3 MSB bits on TC4H, LSB bits on OCR4B
  TC4H = pwm>>8;
  OCR4B = pwm & 0xFF;
}

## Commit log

2017-07-10 Added STL files
    [arm_inner_ring.stl, arm_part1.stl, arm_part2.stl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]
2017-07-10 Added STL license & readme Added schematics PDF
2017-07-10 Added STL license details

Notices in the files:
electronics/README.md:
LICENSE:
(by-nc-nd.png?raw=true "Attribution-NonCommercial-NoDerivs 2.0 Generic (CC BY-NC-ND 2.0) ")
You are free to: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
